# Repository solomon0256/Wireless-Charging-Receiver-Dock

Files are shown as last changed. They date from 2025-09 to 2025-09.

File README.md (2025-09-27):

# Wireless Charging Receiver Dock

A DIY **wireless charging receiver dock**, designed to support the **QI protocol**, with **USB Type‑C male output**. When paired with a wireless charging transmitter, it enables most Type‑C devices to support wireless charging.

---

## 📐 Mechanical Specifications

* Diameter (with shell): **55.6 mm**
* Thickness: **6.1 mm**
* Weight: **16 g**
* Enclosure: 3D printed **PETG** shell

  * Print settings: **0.12 mm layer height**, random Z‑seam
  * Snap‑fit enclosure (tight, difficult to disassemble → assemble only after testing PCB)

---

## ⚡ Electrical Specifications

* Output: **5 V / 1 A**
* Tested stable power: **4.5 W continuous** (long‑term, no audible noise)
* Controller & resonant capacitors operate within datasheet thermal limits
* Receiver coil inductance: **12.6 µH** (common Qi receiver coil)

---

## 🔧 Design Notes

* **Thermal**: Large copper pours on the PCB improve heat dissipation.
* **Magnetic isolation**: Copper planes interfere with wireless charging recognition.

  * Solution: add **two ferrite sheets** → one between coil and copper pour, plus the coil’s own ferrite.
* **Capacitors**: Must use **X7R dielectric** (low temp‑drift) for resonant circuit.
* **Assembly**: No metallic screws in the enclosure (will disturb magnetic field). Shell is snap‑fit only.

---

## 📂 Repository Structure

```
Wireless-Charging-Receiver-Dock/
│
├── 3d shell/                # 3D printable PETG enclosure
├── Altium/                  # Altium source schematic & PCB files
├── BOM location/            # BOM with placement reference
├── Gerber_PCB1_2025-09-27/  # Gerber files for fabrication
├── result/                  # Rendered PCB and schematic images
│   ├── pcb (1).png
│   ├── pcb (2).png
│   └── ...
├── BOM_Board1_Schematic1_2025-09-27.csv  # BOM export (CSV)
├── BOM_charge_docker.xlsx                # BOM spreadsheet
├── SCH_Schematic1_2025-09-27.pdf         # PDF schematic
└── README.md
```

---

## 🖼️ Preview

### PCB Layout

PCB Layout

### Schematic Example

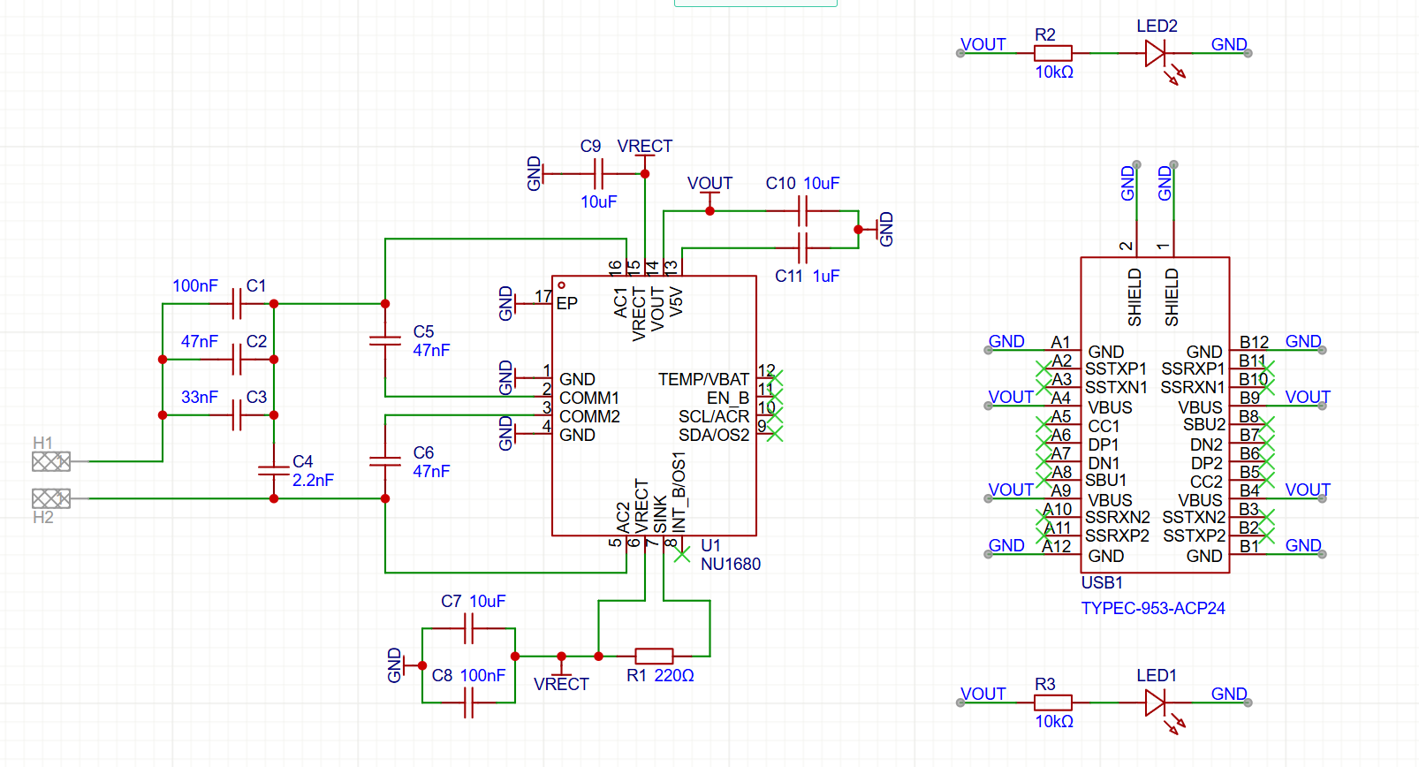
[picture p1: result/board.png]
Schematic


---

## 🚀 Usage Instructions

1. Print the **PETG enclosure** using provided STL/3D files (0.12 mm layer height).
2. Assemble PCB, coil, and ferrite sheets into the enclosure.
3. Connect dock to a Qi transmitter pad.
4. Output available via **USB Type‑C male connector** at **5 V / 1 A**.

---

## ⚠️ Warnings

* Test bare PCB before inserting into snap‑fit shell.
* Always use **ferrite sheet isolation** between coil and copper pour.
* Do not use metal screws or metallic enclosure materials.

---

## 📑 License

Released under the **MIT License**.
You are free to fork, modify, and use in your own hardware builds.

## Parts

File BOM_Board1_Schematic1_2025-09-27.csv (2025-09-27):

No. | Quantity | Comment | Designator | Footprint | Value | Manufacturer Part | Manufacturer | Supplier Part | Supplier | Primary Category | Secondary Category | 3D Model Transform | Current Rating (Max) | Current Rating - Power (Max) | Datasheet
1 | 2 | 100nF | C1,C8 | C0603 | 100nF | 0603B104K500NT | FH(风华) | C30926 | LCSC | 电容 | 贴片电容(MLCC) | 62.992,31.496,0,0,0,0,0,0,0 |  |  | https://atta.szlcsc.com/upload/public/pdf/source/20200305/C486355_26A10D38EF8C2A5C37091D0039909270.pdf
2 | 3 | 47nF | C2,C5,C6 | C0603 | 47nF | 0603B473K500NT | FH(风华) | C285123 | LCSC | 电容 | 贴片电容(MLCC) | 62.992,31.496,0,0,0,0,0,0,0 |  |  | https://atta.szlcsc.com/upload/public/pdf/source/20200305/C486355_26A10D38EF8C2A5C37091D0039909270.pdf
3 | 1 | 33nF | C3 | C0603 | 33nF | CL10B333KB8NNNC | SAMSUNG(三星) | C21117 | LCSC | 电容 | 贴片电容(MLCC) | 62.992,31.496,0,0,0,0,0,0,0 |  |  | https://atta.szlcsc.com/upload/public/pdf/source/20160218/1457707763339.pdf
4 | 1 | 2.2nF | C4 | C0603 | 2.2nF | 0603B222K500NT | FH(风华) | C1604 | LCSC | 电容 | 贴片电容(MLCC) | 62.992,31.496,0,0,0,0,0,0,0 |  |  | https://atta.szlcsc.com/upload/public/pdf/source/20200305/C486355_26A10D38EF8C2A5C37091D0039909270.pdf
5 | 3 | 10uF | C7,C9,C10 | C0603 | 10uF | CL10A106MA8NRNC | SAMSUNG(三星) | C96446 | LCSC | 电容 | 贴片电容(MLCC) | 62.992,31.496,0,0,0,0,0,0,0 |  |  | https://atta.szlcsc.com/upload/public/pdf/source/20160218/1457707763339.pdf
6 | 1 | 1uF | C11 | C0603 | 1uF | CL10A105KB8NNNC | SAMSUNG(三星) | C15849 | LCSC | 电容 | 贴片电容(MLCC) | 62.992,31.496,0,0,0,0,0,0,0 |  |  | https://atta.szlcsc.com/upload/public/pdf/source/20160218/1457707763339.pdf
7 | 2 | MHT192DUGCT | LED1,LED2 | LED0603-RD |  | MHT192DUGCT | MEIHUA(美华) | C7470862 | LCSC | 光电器件 | 发光二极管/LED | 63.7794,32.283,0,0,0,0,0,0,0 |  |  | https://atta.szlcsc.com/upload/public/pdf/source/20231114/40E469906A7C8BE4964C1CB3B5553F65.pdf
8 | 1 | 220Ω | R1 | R0805 | 220Ω | 0805W8J0221T5E | UNI-ROYAL(厚声) | C25294 | LCSC | 电阻 | 贴片电阻 | 78.74,51.181,0,0,0,0,0,-0.0005,0 |  |  | https://atta.szlcsc.com/upload/public/pdf/source/20200306/C422600_1E6D84923E4A46A82E41ADD87F860B5C.pdf
9 | 2 | 10kΩ | R2,R3 | R0603 | 10kΩ | 0603WAF1002T5E | UNI-ROYAL(厚声) | C25804 | LCSC | 电阻 | 贴片电阻 | 31.8897,63.7794,0,90,0,0,0,0,0 |  |  | https://atta.szlcsc.com/upload/public/pdf/source/20200306/C422600_1E6D84923E4A46A82E41ADD87F860B5C.pdf
10 | 1 | NU1680 | U1 | QFN-16_L3.0-W3.0-P0.50-TL-EP1.9 |  | NU1680 |  | C9900015597 | LCSC |  |  | 118.11,118.11,0,0,0,0,0.445,-0.047,0 |  |  | https://atta.szlcsc.comnull
11 | 1 | TYPEC-953-ACP24 | USB1 | USB-C-SMD_TYPEC-953-ACP24 |  | TYPEC-953-ACP24 | XUNPU(讯普) | C2840397 | LCSC | 连接器 | USB连接器 | 340.9442,226.3775,0,0,0,0,-0.002,-0.002,-47.244 |  | 5A | https://atta.szlcsc.com/upload/public/pdf/source/20210712/C2840397_F12B7D151AA3FDBE55F61123537BD469.pdf

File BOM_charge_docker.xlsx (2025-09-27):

ID | Name | Designator | Footprint | Quantity | Manufacturer Part | Manufacturer | Supplier | Supplier Part
1 | 10uF | C10,C9,C7 | C0603 | 3 | CL10A106MA8NRNC | SAMSUNG(三星) | LCSC | C96446
2 | 1uF | C11 | C0603 | 1 | CL10A105KB8NNNC | SAMSUNG(三星) | LCSC | C15849
3 | NU1680 | U1 | QFN-16_L3.0-W3.0-P0.50-TL-EP1.9 | 1 | NU1680 |  | LCSC | C9900015597
4 | 220Ω | R1 | R0805 | 1 | 0805W8J0221T5E | UNI-ROYAL(厚声) | LCSC | C25294
5 | 47nF | C2,C6,C5 | C0603 | 3 | 0603B473K500NT | FH(风华) | LCSC | C285123
6 | 33nF | C3 | C0603 | 1 | CL10B333KB8NNNC | SAMSUNG(三星) | LCSC | C21117
7 | 100nF | C1,C8 | C0603 | 2 | 0603B104K500NT | FH(风华) | LCSC | C30926
8 | 2.2nF | C4 | C0603 | 1 | 0603B222K500NT | FH(风华) | LCSC | C1604
9 | 2.54-1*1P针 | H1,H2 | 2mm-1.3mm孔 | 2 | 2.54-1*1P针 | BOOMELE(博穆精密) | LCSC | C81276
10 | TYPEC-953-ACP24 | USB1 | USB-C-SMD_TYPEC-953-ACP24 | 1 | TYPEC-953-ACP24 | XUNPU(讯普) | LCSC | C2840397
11 | MHT192DUGCT | LED1,LED2 | LED0603-RD | 2 | MHT192DUGCT | MEIHUA(美华) | LCSC | C7470862
12 | 10kΩ | R2,R3 | R0603 | 2 | 0603WAF1002T5E | UNI-ROYAL(厚声) | LCSC | C25804

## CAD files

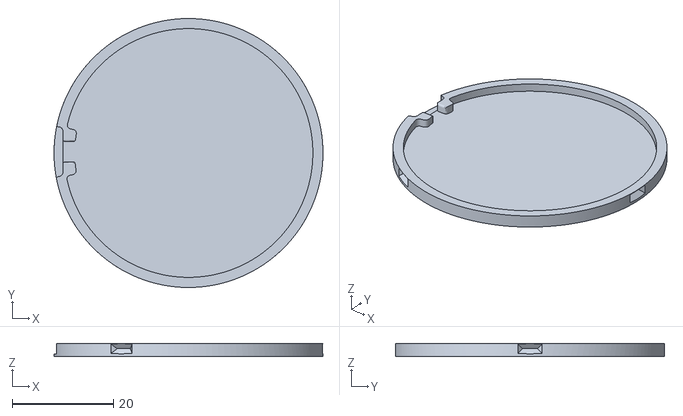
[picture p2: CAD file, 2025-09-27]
3d shell/downshell.stl
53.2 x 53.2 x 2.50

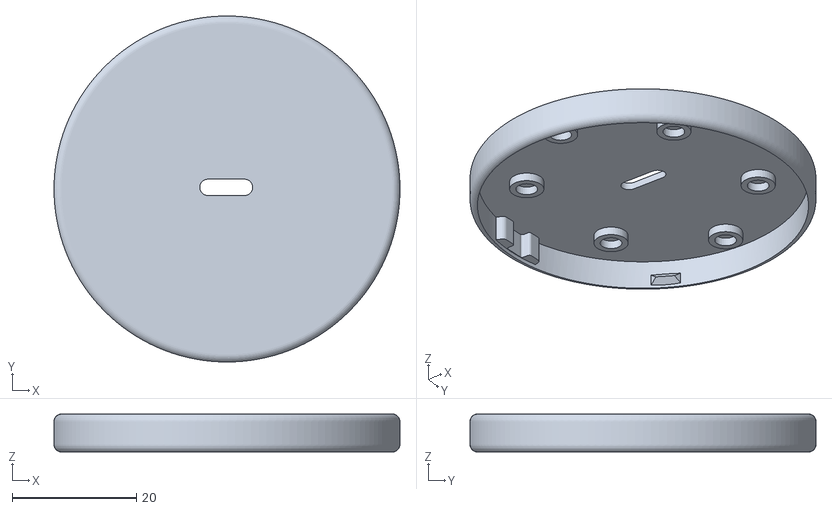
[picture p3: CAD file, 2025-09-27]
3d shell/upshell.stl
55.6 x 55.6 x 6.10

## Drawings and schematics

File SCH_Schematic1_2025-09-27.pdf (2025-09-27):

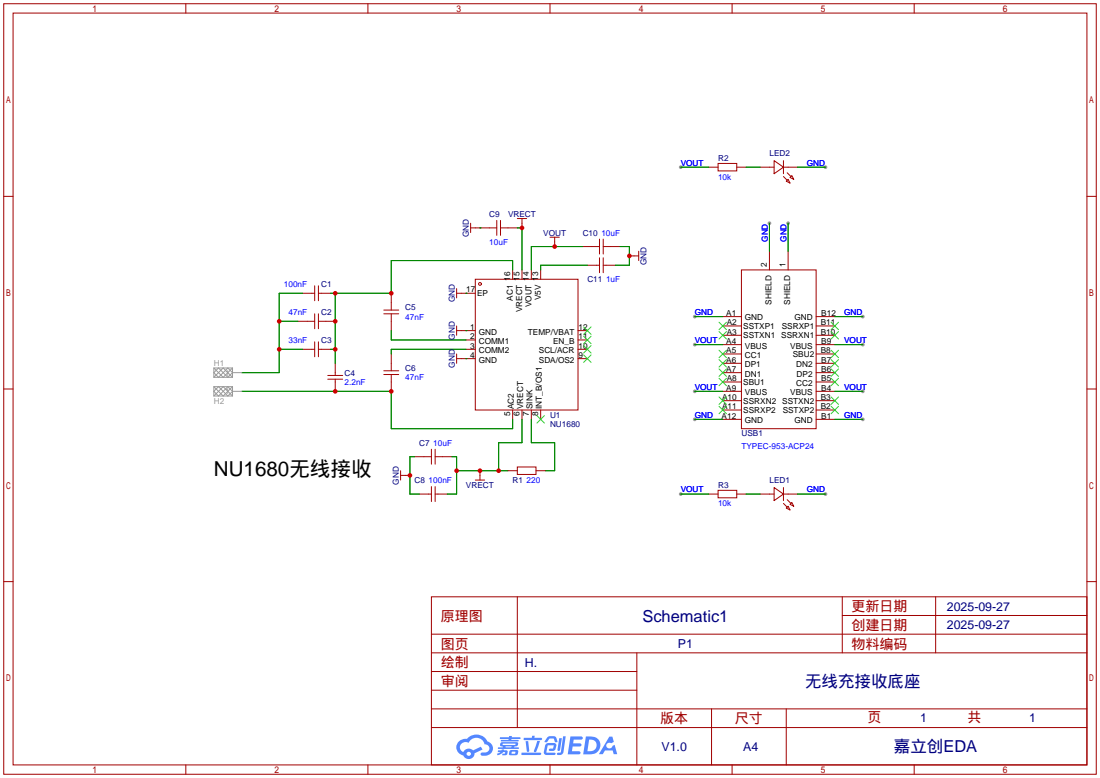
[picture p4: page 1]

SCL/ACR 10 EN_B 11 TEMP/VBAT 12 V⁵V ¹³ VOUT 14

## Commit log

2025-09-27 add picture
    [PCB1.pcbdoc, downshell.stl, upshell.stl]
2025-09-27 change file
    [1_P1.schdoc, BOM_charge_docker.xlsx, PCB1.pcbdoc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]
